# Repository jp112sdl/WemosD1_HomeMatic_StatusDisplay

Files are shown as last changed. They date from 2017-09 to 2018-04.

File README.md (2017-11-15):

# WemosD1 HomeMatic Status Display




## Zusammenfassung:
Ziel dieses Projektes ist der kostengünstige Bau einer Statusanzeige, ähnlich der von HomeMatic angebotenen.

Die Helligkeit der LEDs lässt sich mit einem Taster in 25 Stufen einstellen.

**2 Bilder des ersten Prototypen:**<br>
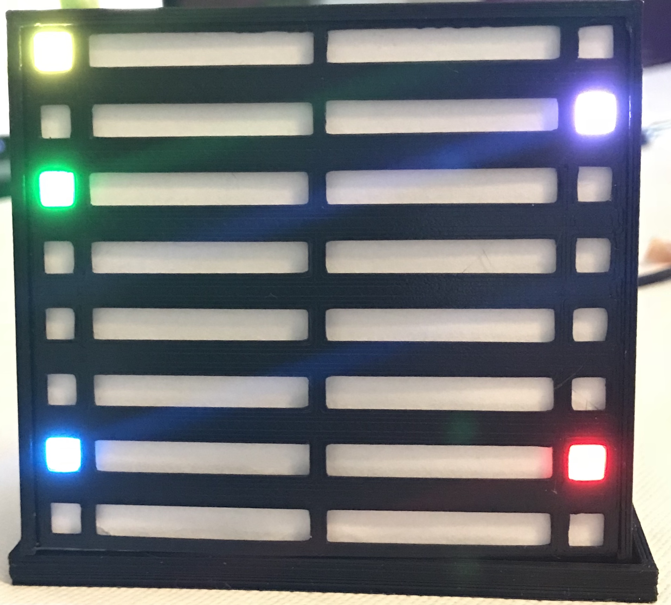
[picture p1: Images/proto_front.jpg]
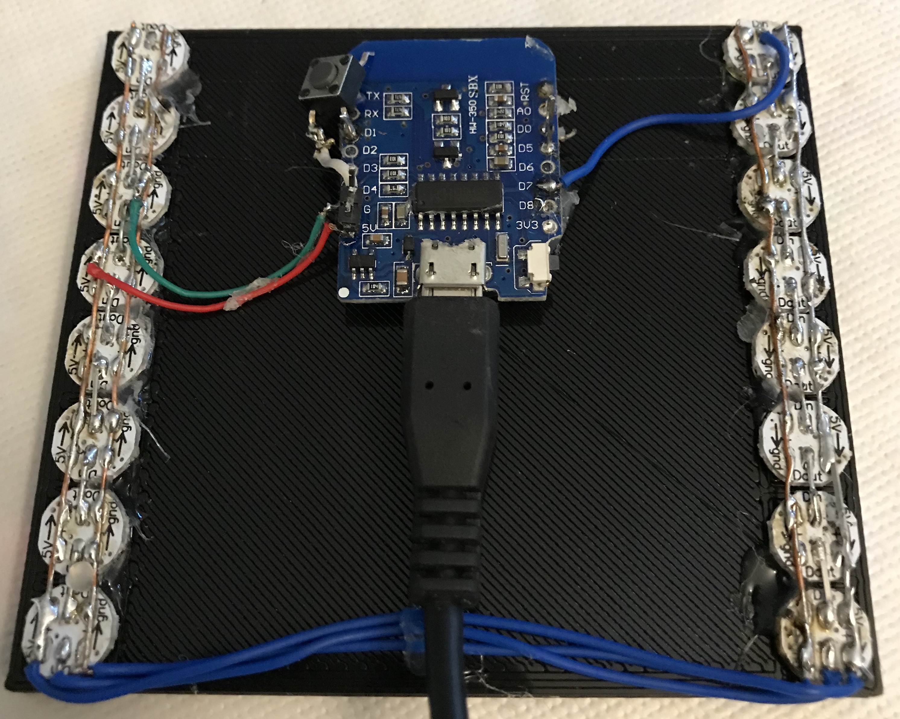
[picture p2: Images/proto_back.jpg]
 

**JETZT NEU: Mit Unterstützung von 16 Tasterkanälen!**<br>
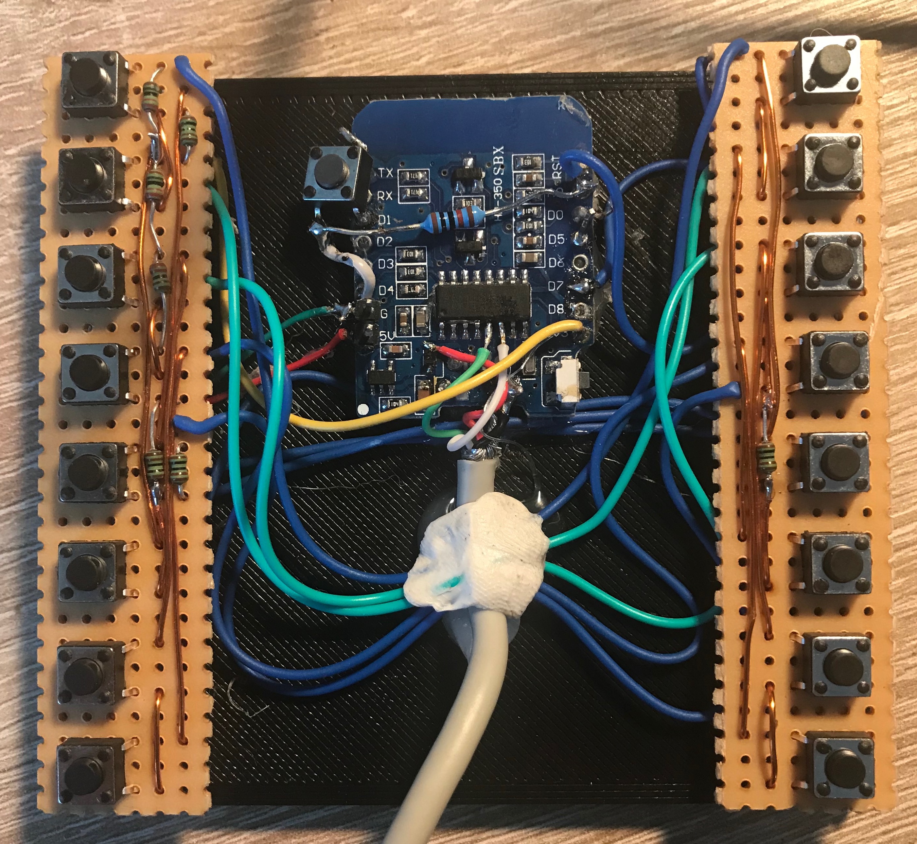
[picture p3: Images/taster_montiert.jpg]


Die komplette Nachbauanleitung findet ihr im [Wiki](https://github.com/jp112sdl/WemosD1_HomeMatic_StatusDisplay/wiki)

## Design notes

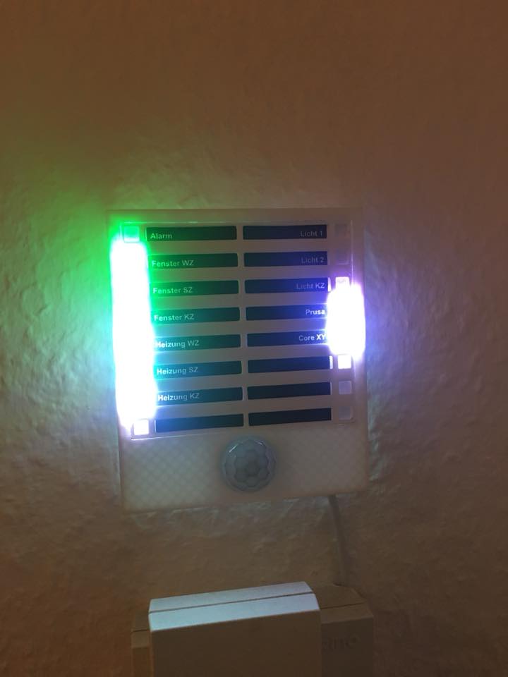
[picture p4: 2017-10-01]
Images/mw/mw_front.jpg

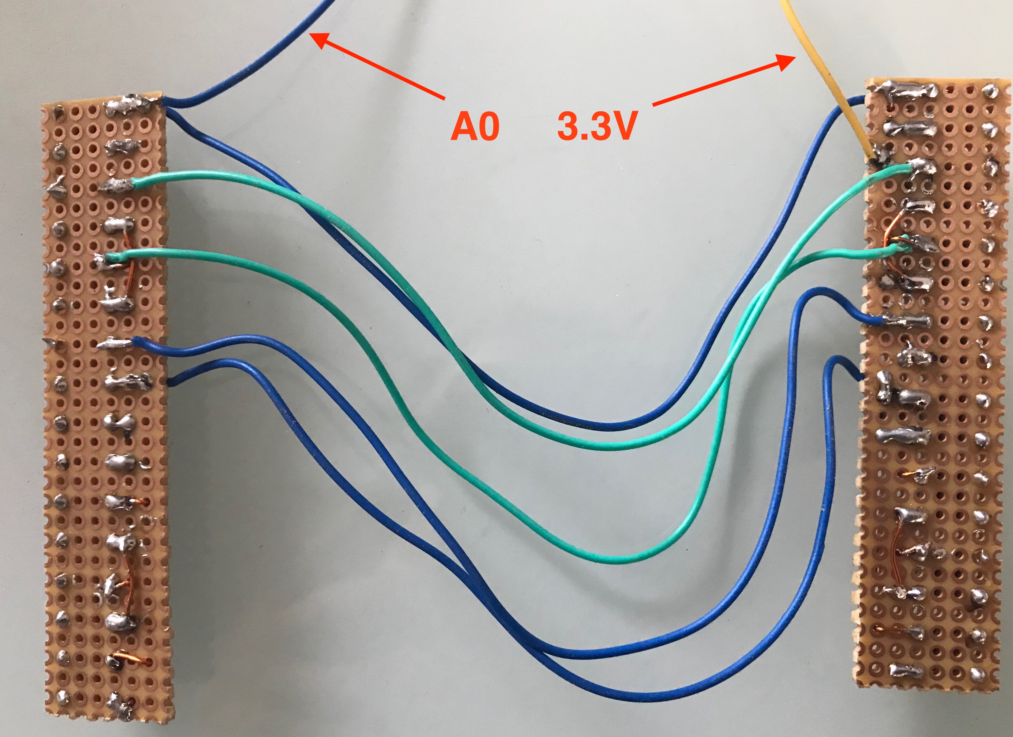
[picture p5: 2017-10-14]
Images/taster_hinten.jpg

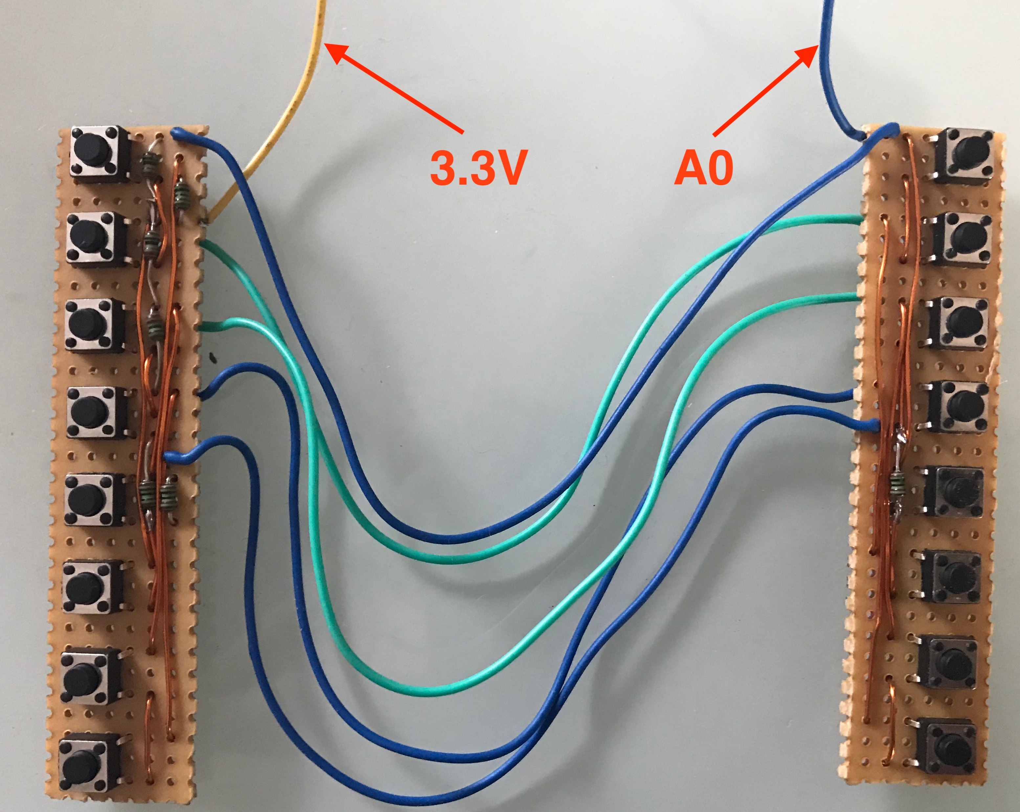
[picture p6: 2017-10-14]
Images/taster_vorn.jpg

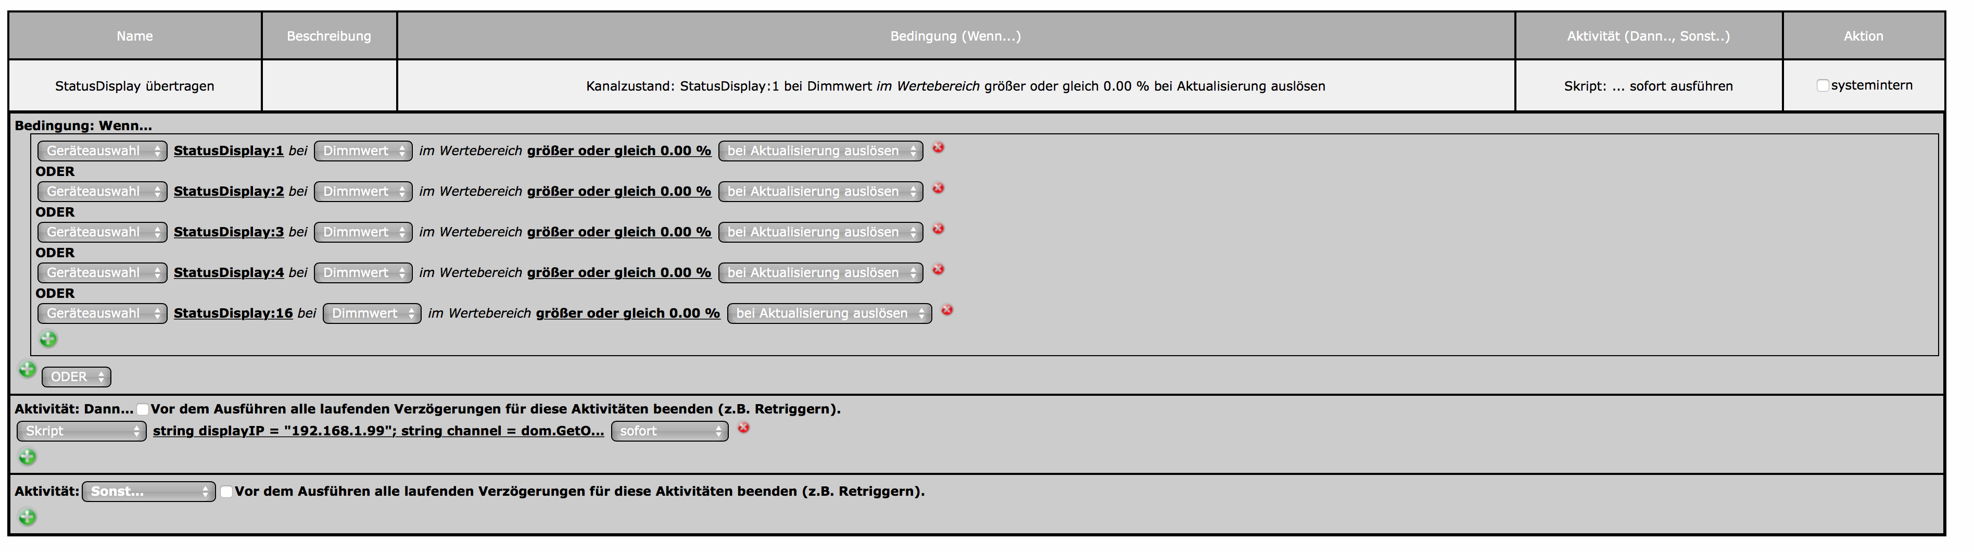
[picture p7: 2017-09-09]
Images/HomeMatic_Programm.png

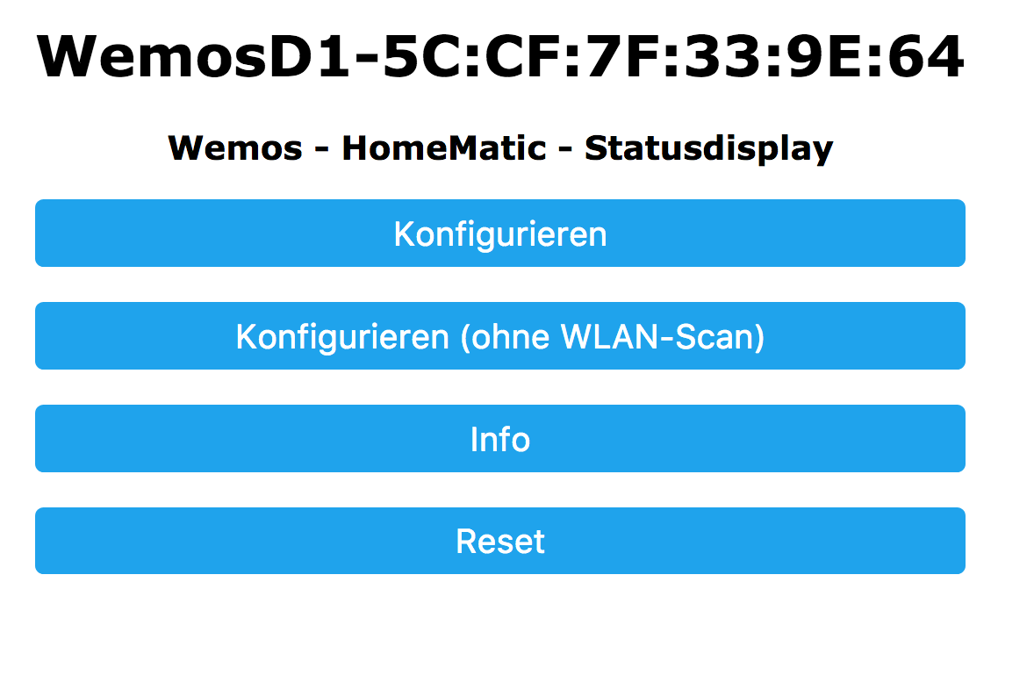
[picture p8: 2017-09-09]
Images/config_start.png

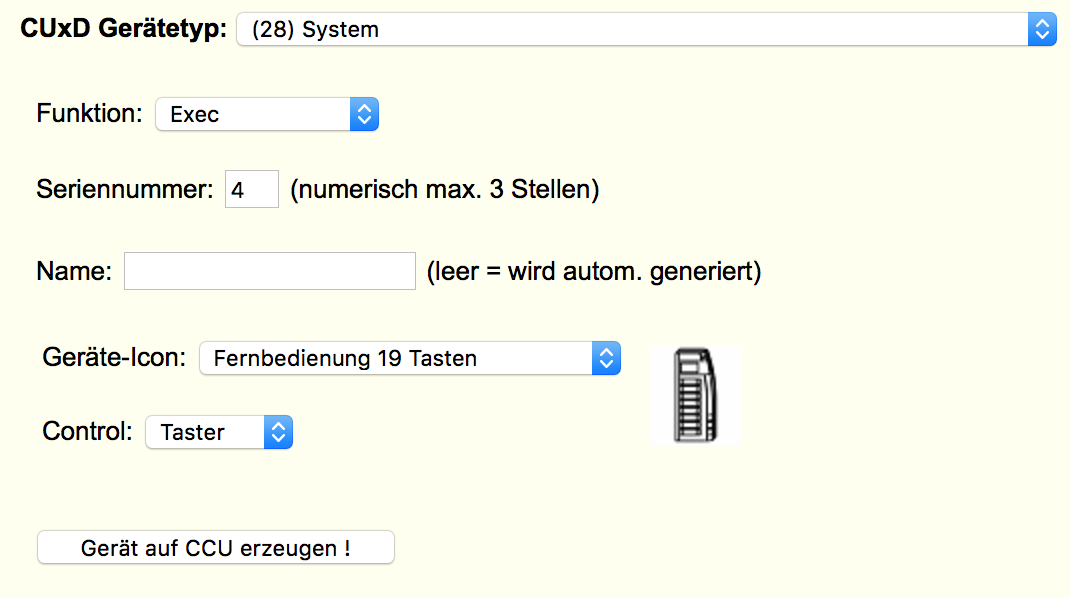
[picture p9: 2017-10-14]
Images/taster_cuxd28.png

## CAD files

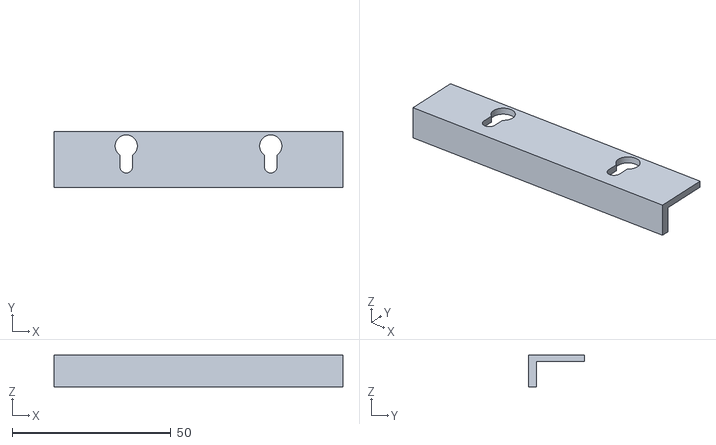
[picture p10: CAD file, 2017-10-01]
Images/mw/mw_StatusDisplay-teil-2.stl
91.0 x 17.5 x 10.0

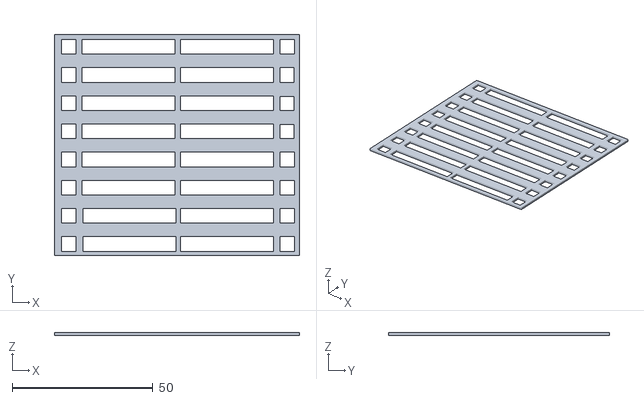
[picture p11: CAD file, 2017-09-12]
Images/Rasterplatte.stl
87.0 x 78.5 x 1.00

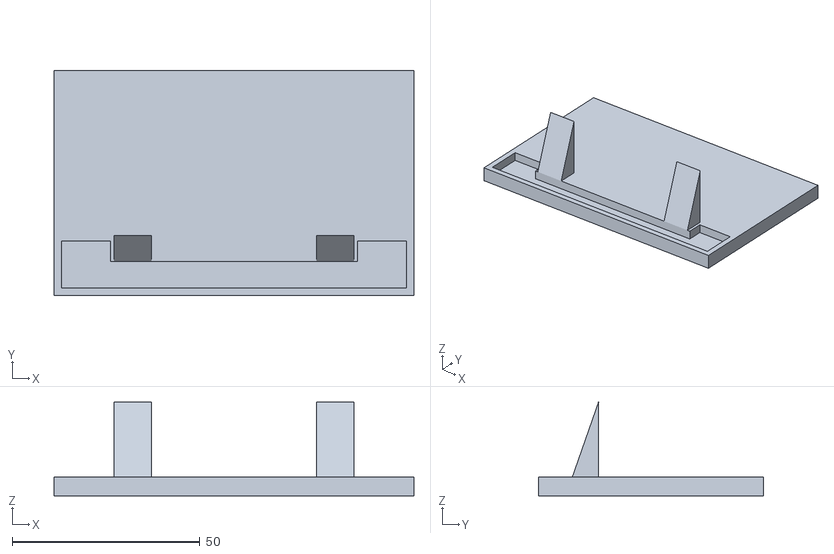
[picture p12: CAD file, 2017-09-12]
Images/Grundplatte.stl
96.0 x 60.0 x 25.0

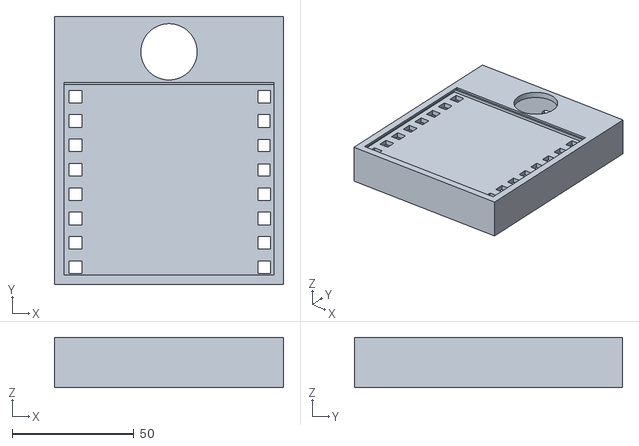
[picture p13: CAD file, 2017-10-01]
Images/mw/mw_StatusDisplay.stl
94.0 x 110.0 x 20.6

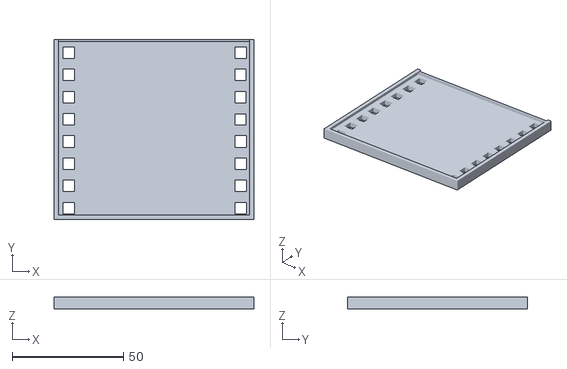
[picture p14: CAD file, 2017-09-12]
Images/Front.stl
90.0 x 81.0 x 5.60

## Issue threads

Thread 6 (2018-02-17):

Taster ohne Funktion

Michel83, 2018-02-17:
Hi,
gibt es was, was ich bei den 16 Tastern noch prüfen kann ich habe sie nach Anleitung angelernt was auch mit der grünen LED bestätigt wurde.
Aber ich bekomme sie nicht zum schalten über die CCU, Gerät ist richtig angelegt und auch überprüft.

Die Statusanzeige Funktioniert ohne Probleme

jp112sdl, 2018-02-17:
Hallo @Michel83 ,

kannst du bitte einen seriellen Log einfügen?
Bitte komplett vom Boot des Gerätes bis zum Drücken eines Tasters.
Vielleicht kann ich daraus schon was erkennen.

Wie man sowas macht, ist hier in einem [Youtube-Video](https://www.youtube.com/watch?v=dO-BMOzNKcI) erklärt.
Bei Speed muss 115200 eingetragen werden.
*Die zusätzlichen Einstellungen ab 1:07 min. brauchst du nicht verändern und kannst einfach schon auf "Open" klicken.*

Nachdem du Open geklickt hast, betätigst du den kleinen schwarzen Taster auf der WemosD1-Platine.
Nun siehst du in Putty die Log-Ausgaben.

Michel83, 2018-02-17:
Grade gemacht, ich glaube der Wemos vergisst irgendwie die Taster Positionen wenn ich den taster eins nach dem Anlernen drücke erkennt er mal 2 mal 5 usw sieht man schön im Log

`
▒
l▒
c|▒▒▒▒c▒c▒▒oo▒doo▒▒▒cp▒dslslp▒o▒▒d▒▒co▒|d▒▒c▒▒oo▒d▒▒d`▒gg
l`gs▒▒▒g
c
▒ds▒▒g
c
▒d▒▒l▒p▒▒d▒n▒Programmstart...
mounting FS...
mounted file system
reading config file
opened config file
{"ip":"192.168.178.55","netmask":"255.255.255.0","gw":"192.168.178.1","ccuip":"192.168.178.70","devicename":"StatusDisplay_1","numleds":16,"eorder":66,"brightness":35,"restorestate":true,"pirtoccu":false,"dimBlink":7,"ledkeys":[746,739,716,709,695,689,682,690,1024,1024,1024,757,764,771,764,756],"color0":"00FF00","color1":"F39C12","color2":"FF0000","color3":"FFFFFF","color4":"0000FF","color5":"00FF00","color6":"F39C12","color7":"FF0000","color8":"FFFFFF","color9":"0000FF"}
parsed json
*WM: Adding parameter
*WM:
*WM: Adding parameter
*WM: numleds
*WM: Adding parameter
*WM: rgborder
*WM: Adding parameter
*WM:
*WM: Adding parameter
*WM: ccuip
*WM: Adding parameter
*WM: devicename
*WM: Adding parameter
*WM: restorestate
*WM: Adding parameter
*WM: pirtoccu
*WM: Adding parameter
*WM:
*WM: Adding parameter
*WM: color1
*WM: Adding parameter
*WM: color2
*WM: Adding parameter
*WM: color3
*WM: Adding parameter
*WM: color4
*WM: Adding parameter
*WM: color5
*WM: Adding parameter
*WM: color6
*WM: Adding parameter
*WM: color7
*WM: Adding parameter
*WM: color8
*WM: Adding parameter
*WM: color9
*WM: Adding parameter
*WM: color10
*WM: Adding parameter
*WM:
*WM: Adding parameter
*WM: dimblink
*WM: Adding parameter
*WM:
*WM: Adding parameter
*WM: custom_ip
*WM: Adding parameter
*WM: custom_netmask
*WM: Adding parameter
*WM: custom_gw
*WM:
*WM: AutoConnect
*WM: Connecting as wifi client...
*WM: Custom STA IP/GW/Subnet
*WM: 192.168.178.55
*WM: Using last saved values, should be faster
*WM: Connection result:
*WM: 0
*WM: SET AP STA
AP-Modus ist aktiv!
*WM:
*WM: Configuring access point...
*WM: WemosD1-A0:20:A6:0A:2F:21
*WM: AP IP address:
*WM: 192.168.4.1
*WM: HTTP server started
*WM: Request redirected to captive portal
*WM: Request redirected to captive portal
*WM: Handle root
*WM: Reset
*WM: Sent reset page

 ets Jan  8 2013,rst cause:2, boot mode:(3,7)

load 0x4010f000, len 1384, room 16
tail 8
chksum 0x2d
csum 0x2d
v0c897c37
~ld
   Programmstart...
mounting FS...
mounted file system
reading config file
opened config file
{"ip":"192.168.178.55","netmask":"255.255.255.0","gw":"192.168.178.1","ccuip":"192.168.178.70","devicename":"StatusDisplay_1","numleds":16,"eorder":66,"brightness":35,"restorestate":true,"pirtoccu":false,"dimBlink":7,"ledkeys":[746,739,716,709,695,689,682,690,1024,1024,1024,757,764,771,764,756],"color0":"00FF00","color1":"F39C12","color2":"FF0000","color3":"FFFFFF","color4":"0000FF","color5":"00FF00","color6":"F39C12","color7":"FF0000","color8":"FFFFFF","color9":"0000FF"}
parsed json
*WM: Adding parameter
*WM:
*WM: Adding parameter
*WM: numleds
*WM: Adding parameter
*WM: rgborder
*WM: Adding parameter
*WM:
*WM: Adding parameter
*WM: ccuip
*WM: Adding parameter
*WM: devicename
*WM: Adding parameter
*WM: restorestate
*WM: Adding parameter
*WM: pirtoccu
*WM: Adding parameter
*WM:
*WM: Adding parameter
*WM: color1
*WM: Adding parameter
*WM: color2
*WM: Adding parameter
*WM: color3
*WM: Adding parameter
*WM: color4
*WM: Adding parameter
*WM: color5
*WM: Adding parameter
*WM: color6
*WM: Adding parameter
*WM: color7
*WM: Adding parameter
*WM: color8
*WM: Adding parameter
*WM: color9
*WM: Adding parameter
*WM: color10
*WM: Adding parameter
*WM:
*WM: Adding parameter
*WM: dimblink
*WM: Adding parameter
*WM:
*WM: Adding parameter
*WM: custom_ip
*WM: Adding parameter
*WM: custom_netmask
*WM: Adding parameter
*WM: custom_gw
*WM:
*WM: AutoConnect
*WM: Connecting as wifi client...
*WM: Custom STA IP/GW/Subnet
*WM: 192.168.178.55
*WM: Using last saved values, should be faster
*WM: Connection result:
*WM: 0
*WM: SET AP STA
AP-Modus ist aktiv!
*WM:
*WM: Configuring access point...
*WM: WemosD1-A0:20:A6:0A:2F:21
*WM: AP IP address:
*WM: 192.168.4.1
*WM: HTTP server started
*WM: Request redirected to captive portal
*WM: Request redirected to captive portal
*WM: Request redirected to captive portal
*WM: Request redirected to captive portal
*WM: Handle root
*WM: Scan done
*WM: DUP AP: WLAN 7270
*WM: DUP AP: WLAN 7270
*WM: WLAN 7270
*WM: -57
*WM: HZN246152378
*WM: -67
*WM: WLAN-218760
*WM: -79
*WM: AndroidAP
*WM: -90
*WM: devolo-e3c
*WM: -91
*WM: Sent config page
*WM: Request redirected to captive portal
*WM: Request redirected to captive portal
*WM: WiFi save
*WM: Parameter
*WM:
*WM:
*WM: Parameter
*WM: numleds
*WM: 16
*WM: Parameter
*WM: rgborder
*WM: 66
*WM: Parameter
*WM:
*WM:
*WM: Parameter
*WM: ccuip
*WM: 192.168.178.70
*WM: Parameter
*WM: devicename
*WM: StatusDisplay_1
*WM: Parameter
*WM: restorestate
*WM: 1
*WM: Parameter
*WM: pirtoccu
*WM:
*WM: Parameter
*WM:
*WM:
*WM: Parameter
*WM: color1
*WM: 00FF00
*WM: Parameter
*WM: color2
*WM: F39C12
*WM: Parameter
*WM: color3
*WM: FF0000
*WM: Parameter
*WM: color4
*WM: FFFFFF
*WM: Parameter
*WM: color5
*WM: 0000FF
*WM: Parameter
*WM: color6
*WM: 00FF00
*WM: Parameter
*WM: color7
*WM: F39C12
*WM: Parameter
*WM: color8
*WM: FF0000
*WM: Parameter
*WM: color9
*WM: FFFFFF
*WM: Parameter
*WM: color10
*WM: 0000FF
*WM: Parameter
*WM:
*WM:
*WM: Parameter
*WM: dimblink
*WM: 7
*WM: Parameter
*WM:
*WM:
*WM: Parameter
*WM: custom_ip
*WM: 192.168.178.55
*WM: Parameter
*WM: custom_netmask
*WM: 255.255.255.0
*WM: Parameter
*WM: custom_gw
*WM: 192.168.178.1
*WM: Sent wifi save page
*WM: Connecting to new AP
*WM: Connecting as wifi client...
*WM: Custom STA IP/GW/Subnet
*WM: 192.168.178.55
*WM: Connection result:
*WM: 4
*WM: Failed to connect.
*WM: Request redirected to captive portal
*WM: Request redirected to captive portal
*WM: Handle root
*WM: Scan done
*WM: DUP AP: WLAN 7270
*WM: DUP AP: WLAN 7270
*WM: WLAN 7270
*WM: -57
*WM: HZN246152378
*WM: -73
*WM: Lasyab
*WM: -92
*WM: Sent config page
*WM: Request redirected to captive portal
*WM: Request redirected to captive portal
*WM: Handle root
*WM: Request redirected to captive portal
*WM: Handle root
*WM: Scan done
*WM: DUP AP: WLAN 7270
*WM: DUP AP: WLAN 7270
*WM: WLAN 7270
*WM: -55
*WM: HZN246152378
*WM: -73
*WM: devolo-c59
*WM: -93
*WM: Lasyab
*WM: -93
*WM: Telekom_FON
*WM: -94
*WM: Sent config page
*WM: Request redirected to captive portal
*WM: Request redirected to captive portal
*WM: WiFi save
*WM: Parameter
*WM:
*WM:
*WM: Parameter
*WM: numleds
*WM: 16
*WM: Parameter
*WM: rgborder
*WM: 66
*WM: Parameter
*WM:
*WM:
*WM: Parameter
*WM: ccuip
*WM: 192.168.178.70
*WM: Parameter
*WM: devicename
*WM: StatusDisplay_1
*WM: Parameter
*WM: restorestate
*WM: 1
*WM: Parameter
*WM: pirtoccu
*WM:
*WM: Parameter
*WM:
*WM:
*WM: Parameter
*WM: color1
*WM: 00FF00
*WM: Parameter
*WM: color2
*WM: F39C12
*WM: Parameter
*WM: color3
*WM: FF0000
*WM: Parameter
*WM: color4
*WM: FFFFFF
*WM: Parameter
*WM: color5
*WM: 0000FF
*WM: Parameter
*WM: color6
*WM: 00FF00
*WM: Parameter
*WM: color7
*WM: F39C12
*WM: Parameter
*WM: color8
*WM: FF0000
*WM: Parameter
*WM: color9
*WM: FFFFFF
*WM: Parameter
*WM: color10
*WM: 0000FF
*WM: Parameter
*WM:
*WM:
*WM: Parameter
*WM: dimblink
*WM: 7
*WM: Parameter
*WM:
*WM:
*WM: Parameter
*WM: custom_ip
*WM: 192.168.178.55
*WM: Parameter
*WM: custom_netmask
*WM: 255.255.255.0
*WM: Parameter
*WM: custom_gw
*WM: 192.168.178.1
*WM: Sent wifi save page
*WM: Connecting to new AP
*WM: Connecting as wifi client...
*WM: Custom STA IP/GW/Subnet
*WM: 192.168.178.55
*WM: Connection result:
*WM: 3
Should save config
Wifi Connected
CUSTOM STATIC IP: 192.168.178.55 Netmask: 255.255.255.0 GW: 192.168.178.1
Custom IP Address is set!
saving config
{"ip":"192.168.178.55","netmask":"255.255.255.0","gw":"192.168.178.1","ccuip":"192.168.178.70","devicename":"StatusDisplay_1","numleds":16,"eorder":66,"brightness":35,"restorestate":true,"pirtoccu":false,"dimBlink":7,"ledkeys":[746,739,716,709,695,689,682,690,1024,1024,1024,757,764,771,764,756],"color0":"00FF00","color1":"F39C12","color2":"FF0000","color3":"FFFFFF","color4":"0000FF","color5":"00FF00","color6":"F39C12","color7":"FF0000","color8":"FFFFFF","color9":"0000FF"}

 ets Jan  8 2013,rst cause:2, boot mode:(3,7)
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
jp112sdl, 2018-02-17:
Ich habe tatsächlich einen Fehler im Code gefunden und *hoffentlich* behoben.

Versuch es bitte mal hiermit:
[WemosD1_HomeMatic_StatusDisplay.ino.d1_mini.bin.zip](https://github.com/jp112sdl/WemosD1_HomeMatic_StatusDisplay/files/1733641/WemosD1_HomeMatic_StatusDisplay.ino.d1_mini.bin.zip)

Was mir noch auffällt: Deine Widerstandswerte liegen alle sehr dicht beieinander. Da kann es zu Fehlauswertungen kommen.
Deine:
`[684,657,652,664,653,628,641,635,1024,1024,1024,674,696,688,681,692]`
Meine:
`[864,845,830,816,927,893,882,881,896,913,926,959,979,994,1019,1020]`

Evtl. hast du noch irgendwo einen Dreher drin...

Michel83, 2018-02-17:
Ja es Funktioniert super vielen Dank für den schnellen Support !!!!

Gruß

jp112sdl, 2018-02-17:
Danke für das positive Feedback!

Michel83, 2018-02-17:
Den Fehler mit den Tastern bei mir habe ich gefunden nur leider beheben ist schwierige da die Heißklebepistole schneller war. Aber in der 2 Version.

Könnte man die Taster auch noch in der Webui hinzufügen ? und eventuell auch Beschriftungsfelder für die LED`s dann wäre das Webui Perfekt und man könnte dieses sogar auf anderen Geräten über http anzeigen z.b. Neo Creator.

Danke nochmal für den Support

Gruß

jp112sdl, 2018-02-17:
Die Weboberfläche ist rudimentär und eigentlich nur nebenbei entstanden.

Wenn ich mal viel Langeweile hab (vielleicht im nächsten Winter ;) ) denk ich mal drüber nach :D

Michel83, 2018-02-20:
Kein Problem, die Anzeige ist auch so schon Top, super sache !!!

Gibt es eigentlich eine Anleitung oder Readme für WemosD1_HomeMatic_FunkGong ? oder habe ich sie einfach nicht gefunden ?

Sorry das ich das einfach jetzt hier mal so reinschreibe

jp112sdl, 2018-02-20:
Gibts nicht. Hab ich nur nach Anregung von [Braindead](https://github.com/braindead1/WemosD1_MP3Gong) für mich abgewandelt und um einen rotierenden/umlaufenden LED-Kranz erweitert.

Closed 2018-02-17.

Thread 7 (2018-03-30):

Taster

Michel83, 2018-03-30:
Hi,

ich hätte noch ein kleines Problem wo ich nicht weiter komme.
Es geht um die Taster es ist jetzt so das die Werte bei allen unterschiedlich sind allerdings werden sie von dem Wemos nicht erkannt er sagt immer bei jedem taster 1024 erkannt.

Hier ein paar Bilder wenn ich am A0 des Wemos mit dem Multimeter messe, was ich festgestellt habe das es ein moment dauert bis der Multimeter den Wert anzeigt.

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

jp112sdl, 2018-03-30:
Schließ den + mal bitte statt an 5V an den **3.3V** Pin des Wemos. Ich glaub das ist in meinem Schaltplan falsch.

Michel83, 2018-03-30:
Super danke das war es, läuft :-)

jp112sdl, 2018-03-30:
Danke für den Hinweis. Habs im Schaltplan jetzt auch geändert.

Michel83, 2018-03-30:
Kein Problem, echt super das Teil.

Die LED's sind noch ein wenig Hell :-)

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

jp112sdl, 2018-03-30:
> Die LED's sind noch ein wenig Hell

Das kannst du ja beliebig einstellen :)

Closed 2018-03-30.

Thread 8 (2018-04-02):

Display friert ein

Michel83, 2018-04-02:
Hi,

ich muss leider nochmal nerven. Habe noch das Problem das der Wemos hin und wieder nicht mehr erreichbar ist. Hatte dies auch schon bei meiner ersten Bastel version, dachte es läge aber an meinem Wemos weil eben Bastel.

Aber mein jetziger macht das gleiche, es ist dann so das auch die LED´s nicht mehr aktualisiert werden erst wenn ich am Display irgendeine taste drücke ist es so als ob der Wemos neu startet also die Blinkreinfolge der LED´s und danach alles wieder in Ordnung.

Gruß
Mike

jp112sdl, 2018-04-02:
Hast du den Code selbst kompiliert oder die .bin geflasht?

Michel83, 2018-04-02:
Die .bin geflasht wie in der Anleitung

jp112sdl, 2018-04-02:
Ich vermute, das Problem hängt mit esp8266/Arduino#2330 zusammen.

Teste bitte mal diese hier:
[WemosD1_HomeMatic_StatusDisplay.ino.d1_mini.bin.zip](https://github.com/jp112sdl/WemosD1_HomeMatic_StatusDisplay/files/1867526/WemosD1_HomeMatic_StatusDisplay.ino.d1_mini.bin.zip)

Michel83, 2018-04-02:
Ich teste

Michel83, 2018-04-02:
Bis jetzt ist noch alles gut, ist das `WiFi.setSleepMode(WIFI_NONE_SLEEP);` die Änderung in dem WLAN gewesen ?
Weil ich habe noch einen Wemos als ir remote der die gleichen Bauchweh hat dann würde ich das da auch mal versuchen

jp112sdl, 2018-04-02:
Hab die Änderungen gepusht, damit du nachschauen kannst

Michel83, 2018-04-04:
Ich denke es läuft seit dem keine Einfrierer mehr, danke für die Anpassung.
Ich glaub bis ich da alles verstehe dauert noch ein Moment :-)

Gruß
Mike

jp112sdl, 2018-04-04:
Perfekt 👍
Dann viel Spaß damit - ich mach hier zu :)

Closed 2018-04-04.

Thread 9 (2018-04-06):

WiFi Ändern geht nicht bzw. wird ignoriert

guybrushix, 2018-04-06:
Hallo,

ich möchte bei dem Display das WiFi ändern leider nutzt der Wemos immer das alte egal ich wie oft ich das ändere über AP Modus. Das selbe Problem habe ich mit einem (nicht allen) Sonoff POW.

gibt es irgend einen weg ohne komplettes neues flashen ?

Danke im Voraus & Gruss

Michael

jp112sdl, 2018-04-06:
Nein, die Wifi Zugangsdaten liegen in einem anderen Speicherbereich, der beim Flashen nicht überschrieben wird. Ein Neuflashen würde also auch nicht die Wifi Daten überschreiben.

Evtl. ist ein Sonderzeichen im Passwort, das bei der Übergabe im HTTP-Get Probleme macht... Die Zugangsdaten werden erst dann gespeichert, wenn beim Speichern auch eine Verbindung zum WLAN mit den eingegebenen Daten hergestellt werden kann. Klappt dies nicht, bleiben die alten erhalten.

jp112sdl, 2018-04-06:
Es könnte jedoch auch mit einem Bug im Wifi Stack selbst zusammenhängen...
Hab da grad was gefunden. esp8266/arduino#4476

guybrushix, 2018-04-07:
Okay dann macht flashen keinen sinn.
Zu

> Evtl. ist ein Sonderzeichen im Passwort, das bei der Übergabe im HTTP-Get Probleme macht...
 im neuen WLAN ist das Passwort eine reine Buchstaben Kombination.

guybrushix, 2018-04-07:
Hallo ich musste wohl das andere WiFi komplett ausschalten sonst hat er sich immer wieder mit dem alten verbunden. Nachdem das alte aus war hat sich das display mit dem neuen WiFi verbunden.

Closed 2018-04-07.

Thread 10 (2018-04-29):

2 Display Kanal 8

Michel83, 2018-04-29:
Ich habe gestern ein zweites Display quasi in Betrieb genommen allerdings ohne taster. Das Problem ist der Kanal 8 es funktionieren alle bis auf diesen. Wenn ich jetzt den Wert beim ersten Display des Kanal 8 verändere, ändert sich die Anzeige auf beiden Displays.

Hab ich irgendwas falsch gemacht ?

jp112sdl, 2018-04-29:
Das kann ich nur anhand der beschriebenen Symptomatik schwer beurteilen.

Evtl. versehentlich IP doppelt vergeben?
Arbeitest du mit UDP oder HTTP Steuerung?
Ist der Gerätename eindeutig?

Michel83, 2018-04-29:
Stimmt recht wenige Informationen

Also die HTTP Steuerung Funktioniert grade getestet, es passiert nur wenn ich diese über die CCU schalte
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

Es passiert auch wenn ich es direct in den Geräten bediene

jp112sdl, 2018-04-29:
Dann kommt ja nur eins in Frage:
Du hast ja 2 Programme. Für jedes StatusDisplay eines.
In den Programmen hast du jeweils alle 16 Kanäle des CUxD Geräts drin.
Ich vermute, dass du versehentlich in Programm 2 für StatusDisplay_2 auch noch einen Kanal von StatusDisplay_1 mit hinzugefügt hast. Oder umgekehrt - in Programm 1 für StatusDisplay_1 versehentlich einen Kanal aus StatusDisplay_2

Michel83, 2018-04-29:
Die Programme sind in Ordnung kann auch noch mal screenshots einstellen, was ich eben auch festgestellt habe das bei der Manuellen Bedienung in der CCU  der Kanal 8 bei dem zweiten Display auch nicht funktioniert. Sondern nur wenn ich den Kanal bei dem ersten Display Wechsel. Ich hatte auch grade zum test das Programm nochmal gelöscht und neu angelegt hat aber auch nichts geholfen

jp112sdl, 2018-04-29:
Also wenn du bspw über einen Browser den Status setzt mit
`http://<ip_display_1>/set?led=8&dim=10`
dann ändert sich die Farbe auf Kanal 8 **nur von  Display 1** entsprechend dem Dimmerwert 10...19?
Und wenn du mit
`http://<ip_display_2>/set?led=8&dim=10`
das selbe für Display 2 machst, ändert sich auch **nur auf Display 2** der Kanal 8?

Michel83, 2018-04-29:
Jetzt habe ich grade nochmal das Programm des ersten Displays gelöscht und neu eingegeben jetzt läuft es :-/ anscheinend ist in der CCU beim kopieren des Programms von Display 1 zu 2 was schief gegangen.

Danke für den Support !!!
Grüße

jp112sdl, 2018-04-29:
Hehe, ja also einen Fehler im Code hatte ich auch ausgeschlossen. Es konnte nur irgendwo von der Zentralensteuerung kommen...

Wenns jetzt geht ist ja alles gut :)
Viel Spaß damit!

Michel83, 2018-04-29:
Danke noch mal, ich habe auch eine weitere Version des Displays zum Einbau ohne taster gezeichnet https://www.thingiverse.com/thing:2882182

jp112sdl, 2018-04-29:
Hab ich mit in der Wiki-Navbar aufgenommen.
https://github.com/jp112sdl/WemosD1_HomeMatic_StatusDisplay/wiki/Housing_Michel83
Danke.

Closed 2018-04-29.

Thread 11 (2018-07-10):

Werte von CCU beim Start laden?

spaceduck518, 2018-07-10:
wie funktioniert das laden der aktuellen Werte aus der CCU? Das aktivieren der Option bewirkt kein holen der Werte beim Start des Displays. IP ist korrekt.

jp112sdl, 2018-07-10:
Der Gerätename muss identisch sein mit dem Namen des CUxD Gerätes, das die Dimmerkanäle hat.
Angenommen du trägst als Gerätenamen **StatusDisplay1** ein, dann muss das CUxD Gerät auch so heißen.
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

Beim Starten wird die Adresse des CUxD-Geräts mit dem Gerätenamen des Statusdisplays gesucht und anschließend werden die Werte der einzelnen Kanäle abgefragt.

spaceduck518, 2018-07-13:
Beide Namen sind identisch, das hatte ich bereits überprüft. Gibt es sonst noch Einstellungen in der CCU oder im CuxD die hier greifen könnten?

spaceduck518, 2018-07-13:
Habe gerade mal den Namen auf beiden Seiten von "StatusDisplay" auf "StatusDisplay1" geändert - funktioniert! Nur "StatusDisplay" ohne Nummer funktioniert nicht. Kannst Du das evtl. ebenfalls bei Dir mal testen / reproduzieren?

spaceduck518, 2018-07-13:
Nein, der Name existiert nicht doppelt, hatte ich ebenfalls schon geprüft. Aber ich kann mit dem workaround leben, kein Problem!

Jan

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

jp112sdl, 2018-07-13:
Ok, dann belassen wir es dabei?
Anderenfalls könntest du auch mal die seriellen Debugmeldungen am PC loggen, dann würden wir wahrscheinlich mehr sehen, weshalb es nicht klappt.

spaceduck518, 2018-07-13:
Ja, wir lassen es so. Ich werde bei Gelegenheit mal via rs232 schauen was da passiert und melde mich dann nochmal.

Danke!

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

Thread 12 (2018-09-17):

Farbe wechseln, nur eine LED möglich?

MathiasJZ, 2018-09-17:
Ich möchte mir so ein Status-Display in der Nähe des Balkonfensters aufhängen.
Aber es soll nur eine LED haben, die von grün auf rot wechselt.
Das ganze soll als "Status Display" für meinen "Einbruchmelder" dienen, wenn scharf geschaltet wurde.
D.h. wenn die Lampe grün leuchtet, darf die Türe geöffnet werden, wenn rot, dann nicht.
Leider gibt es wohl keine Möglichkeit, Fragen zu stellen. Im homematic-forum habe ich diesbezüglich nichts gefunden.
Ein echtes 16-Kanal-Statusdisplay kommt für mich nicht in Frage. ich habe die Visualisierung des Hauses schon per IObroker und Wandtablet umgesetzt.
Gruß,
Mathias

MathiasJZ, 2018-09-18:
Dankeschön für die Antwort.
Da werde ich mich gleich drum kümmern

Gruß
Mathias

Am 18. September 2018 08:21:41 schrieb Jérôme <notifications@github.com>:
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

Closed 2018-09-21.

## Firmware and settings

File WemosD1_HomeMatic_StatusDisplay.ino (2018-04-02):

#include <ArduinoJson.h>
#include <ArduinoOTA.h>
#include <ESP8266HTTPClient.h>
#include <ESP8266HTTPUpdateServer.h>
#include <ESP8266WiFi.h>
#include <ESP8266WebServer.h>
#include <FastLED.h>
#include <FS.h>
#include <WiFiUdp.h>
#include "WM_Custom.h"
#include "global_css.h"
#include "webConfigHTML.h"

#define                       SERIALDEBUG
//#define                       WM_DEBUG_OUTPUT
//#define                       UDPDEBUG

#define CONFIG_PIN            D1
#define PIR_PIN               D5
#define WEBSERVER_PORT        80
#define UDPPORT             6690
#define HTTPGETTIMEOUT      2000 // 2 Sekunden Timeout für Anfragen an die CCU
#define KEYPRESSLONGMILLIS  1500 // ms für langen Tastendruck
#define KEYBOUNCEMILLIS      200 // ms Mindestzeit zwischen 2 Tastendrücken
#define KEYTOLERANCE          5 // +/-Toleranz für 16er Widerstands-/Tastermatrix

#ifdef UDPDEBUG
const char * SYSLOGIP = "192.168.1.251";
#define SYSLOGUDPPORT   514
#endif

enum _SyslogSeverity {
  _slEmergency,
  _slAlert,
  _slCritical,
  _slError,
  _slWarning,
  _slNotice,
  _slInformational,
  _slDebug
};

// FastLED
#define LED_PIN D7
#define LED_TYPE WS2812
#define MAX_LEDS 255
struct led_t {
  CRGB leds[MAX_LEDS];
  CRGB ledsBackup[MAX_LEDS];
  int  Colors[MAX_LEDS];
  bool Blink[MAX_LEDS];
  int  Keys[16] {1023, 1023, 1023, 1023, 1023, 1023, 1023, 1023, 1023, 1023, 1023, 1023, 1023, 1023, 1023, 1023};
} LEDConfig;

enum _EOrder {
  _RGB = 0012,
  _RBG = 0021,
  _GRB = 0102,
  _GBR = 0120,
  _BRG = 0201,
  _BGR = 0210
};
#define IP_SIZE        16
#define VARIABLE_SIZE  100

struct globalconfig_t {
  byte LedBrightness = 255;
  int SelectedEOrder = _RGB;
  int NumLeds =        16;
  char CcuIp[IP_SIZE];
  char DeviceName[VARIABLE_SIZE];
  bool RestoreStateFromCCU = false;
  bool PIRtoCCU = false;
  byte DimBlink = 11;
} GlobalConfig;

#define HEXARRAY_SIZE  24
#define COLOR_COUNT    10

String Dimmer2ColorDefinition[COLOR_COUNT] {
  "00FF00", "F39C12", "FF0000", "FFFFFF", "0000FF", "00FF00", "F39C12", "FF0000", "FFFFFF", "0000FF"
};

enum DisplayStates {
  Sleep,
  Wake
};

ESP8266WebServer WebServer(WEBSERVER_PORT);
ESP8266HTTPUpdateServer httpUpdater;

//UDP
struct udp_t {
  WiFiUDP UDP;
  char incomingPacket[255];
} UDPClient;

//WifiManager - don't touch
byte configPortalTimeout    = 180;
bool shouldSaveConfig       = false;
String configJsonFile   = "config.json";
char ip[IP_SIZE]             = "0.0.0.0";
char netmask[IP_SIZE]        = "0.0.0.0";
char gw[IP_SIZE]             = "0.0.0.0";
boolean startWifiManager    = false;
bool WiFiConnected = false;

int DisplayTimeoutSeconds = 0;
unsigned long LastDisplayTimeOutMillis = 0;
unsigned long LastBlinkMillis = 0;
bool OTAStart = false;
bool DisplayState = Wake;
bool blinkState = false;
bool UDPReady = false;
volatile byte PIRInterruptDetected = 0;
bool ConfigKeyPress = false;
bool ConfigKeyPressLONG = false;
unsigned long ConfigKeyPressDownMillis = 0;
unsigned long LastMillisConfigKeyPress = 0;
unsigned long LastWiFiReconnectMillis = 0;

void setup() {
  pinMode(A0, INPUT);
  pinMode(CONFIG_PIN, INPUT_PULLUP);
  pinMode(LED_BUILTIN, OUTPUT);
  initPIR();

  digitalWrite(LED_BUILTIN, HIGH);
#ifdef SERIALDEBUG
  Serial.begin(115200);
#endif
  DEBUG("Programmstart...");

  if (digitalRead(CONFIG_PIN) == LOW) {
    DEBUG("Taster gedrückt - Config Mode wird gestartet!");
    startWifiManager = true;
    bool state = LOW;
    for (int i = 0; i < 7; i++) {
      state = !state;
      digitalWrite(LED_BUILTIN, state);
      delay(100);
    }
  }
  loadSystemConfig();

  if (doWifiConnect()) {
    DEBUG("WLAN erfolgreich verbunden!");
    printWifiStatus();
  } else ESP.restart();

  startWebServer();

  initUDPClient();

  initLEDs();

  showLedBootSequence();

  startOTAhandling();

  if (GlobalConfig.RestoreStateFromCCU)
    getValuesFromCCU();

  DEBUG(String(GlobalConfig.DeviceName) + " - Boot abgeschlossen, SSID = " + WiFi.SSID() + ", IP = " + String(IpAddress2String(WiFi.localIP())) + ", RSSI = " + WiFi.RSSI() + ", MAC = " + WiFi.macAddress(), "Setup", _slInformational);
}

void loop() {
  if (LastDisplayTimeOutMillis > millis())
    LastDisplayTimeOutMillis = millis();
  if (LastBlinkMillis > millis())
    LastBlinkMillis = millis();
  if (LastWiFiReconnectMillis > millis())
    LastWiFiReconnectMillis = millis();

  //Reconnect WiFi wenn nicht verbunden (alle 30 Sekunden)
  if (WiFi.status() != WL_CONNECTED) {
    WiFiConnected = false;
    if (millis() - LastWiFiReconnectMillis > 30000) {
      LastWiFiReconnectMillis = millis();
      DEBUG("WiFi Connection lost! Reconnecting...");
      WiFi.reconnect();
    }
  } else {
    if (!WiFiConnected) {
      DEBUG("WiFi reconnected!");
      WiFiConnected = true;
    }
  }

  ArduinoOTA.handle();

  if (!OTAStart) {
    WebServer.handleClient();

    handleUDP();

    handlePIR();

    handleKEY();

    if (DisplayTimeoutSeconds > 0 && DisplayState == Wake && millis() - LastDisplayTimeOutMillis > DisplayTimeoutSeconds * 1000) {
      LastDisplayTimeOutMillis = millis();
      DEBUG("Display Timeout", "loop()", _slInformational);
      setLedMode(Sleep);
    }

    if (millis() - LastBlinkMillis > 1000 && DisplayState == Wake) {
      LastBlinkMillis = millis();
      blinkState = !blinkState;
      for (int i = 0; i < GlobalConfig.NumLeds; i++) {
        LEDConfig.ledsBackup[i] = LEDConfig.leds[i];
        if (blinkState && LEDConfig.Blink[i]) {
          LEDConfig.leds[i] = CRGB::Black;
        }
      }
      FastLED.show();
      for (int i = 0; i < GlobalConfig.NumLeds; i++) {
        LEDConfig.leds[i] = LEDConfig.ledsBackup[i];
      }
    }

    //Tasterbedienung CONFIG_PIN
    if (digitalRead(CONFIG_PIN) == LOW) {
      if (!ConfigKeyPress) {
        ConfigKeyPressDownMillis = millis();
        if (millis() - LastMillisConfigKeyPress > KEYBOUNCEMILLIS) {
          LastMillisConfigKeyPress = millis();
          ConfigKeyPress = true;
        }
      }

      if ((millis() - ConfigKeyPressDownMillis) > KEYPRESSLONGMILLIS && !ConfigKeyPressLONG) {
        //PRESS_LONG
        DEBUG("ConfigKeyPress LONG", "loop()", _slInformational);
        ResistorConfigKeys();
        ConfigKeyPressLONG = true;
      }
    } else {
      if (ConfigKeyPress) {
        if ((millis() - ConfigKeyPressDownMillis) < KEYPRESSLONGMILLIS) {
          int brightness = GlobalConfig.LedBrightness;
          brightness = brightness + 25;
          if (brightness > 255) brightness = 10;
          DEBUG("ConfigKeyPress SHORT, setting brightness to " + String(brightness), "loop()", _slInformational);
          setLedBrightness(brightness);
          delay(10); //Entprellen
        }
      }
      ConfigKeyPress = false;
      ConfigKeyPressLONG = false;
    }
    delay(10); //wg. UDP
  }
}

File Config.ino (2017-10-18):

bool loadSystemConfig() {
  DEBUG("mounting FS...", "loadSystemConfig()", _slInformational);
  if (SPIFFS.begin()) {
    DEBUG("mounted file system", "loadSystemConfig()", _slInformational);
    if (SPIFFS.exists("/" + configJsonFile)) {
      DEBUG("reading config file", "loadSystemConfig()", _slInformational);
      File configFile = SPIFFS.open("/" + configJsonFile, "r");
      if (configFile) {
        DEBUG("opened config file", "loadSystemConfig()", _slInformational);
        size_t size = configFile.size();
        std::unique_ptr<char[]> buf(new char[size]);
        configFile.readBytes(buf.get(), size);
        DynamicJsonBuffer jsonBuffer;
        JsonObject& json = jsonBuffer.parseObject(buf.get());
#ifdef SERIALDEBUG
        json.printTo(Serial);
        Serial.println();
#endif
        if (json.success()) {
          DEBUG("parsed json", "loadSystemConfig()", _slInformational);
          ((json["ip"]).as<String>()).toCharArray(ip, IP_SIZE);
          ((json["netmask"]).as<String>()).toCharArray(netmask, IP_SIZE);
          ((json["gw"]).as<String>()).toCharArray(gw, IP_SIZE);
          ((json["ccuip"]).as<String>()).toCharArray(GlobalConfig.CcuIp, IP_SIZE);
          ((json["devicename"]).as<String>()).toCharArray(GlobalConfig.DeviceName, VARIABLE_SIZE);

          json["ledkeys"].asArray().copyTo(LEDConfig.Keys);

          GlobalConfig.RestoreStateFromCCU = json["restorestate"];
          GlobalConfig.PIRtoCCU = json["pirtoccu"];

          for (int i = 0; i < COLOR_COUNT; i++) {
            String colorStr = (json["color" + String(i)]).as<String>();
            if (colorStr != "")
              Dimmer2ColorDefinition[i] = colorStr;
          }

          GlobalConfig.NumLeds = (json["numleds"]).as<int>();
          if (GlobalConfig.NumLeds == 0)
            GlobalConfig.NumLeds = 1;

          GlobalConfig.DimBlink = (json["dimBlink"]).as<byte>();
          if (GlobalConfig.DimBlink == 0) GlobalConfig.DimBlink = 11;

          GlobalConfig.SelectedEOrder = (json["eorder"]).as<int>();
          GlobalConfig.LedBrightness = (json["brightness"]).as<byte>();
          if (GlobalConfig.LedBrightness < 5) GlobalConfig.LedBrightness = 255;

        } else {
          DEBUG("failed to load json config", "loadSystemConfig()", _slError);
        }
      }
      return true;
    } else {
      DEBUG("/" + configJsonFile + " not found.", "loadSystemConfig()", _slWarning);
      return false;
    }
    SPIFFS.end();
  } else {
    DEBUG("failed to mount FS", "loadSystemConfig()", _slError);
    return false;
  }
}

bool saveSystemConfig() {
  SPIFFS.begin();
  DEBUG("saving config", "saveSystemConfig()", _slInformational);
  DynamicJsonBuffer jsonBuffer;
  JsonObject& json = jsonBuffer.createObject();
  json["ip"] = ip;
  json["netmask"] = netmask;
  json["gw"] = gw;
  json["ccuip"] = GlobalConfig.CcuIp;
  json["devicename"] = GlobalConfig.DeviceName;
  json["numleds"] = GlobalConfig.NumLeds;
  json["eorder"] = GlobalConfig.SelectedEOrder;
  json["brightness"] = GlobalConfig.LedBrightness;
  json["restorestate"] = GlobalConfig.RestoreStateFromCCU;
  json["pirtoccu"] = GlobalConfig.PIRtoCCU;
  json["dimBlink"] = GlobalConfig.DimBlink;

  JsonArray& ledkeys = jsonBuffer.createArray();
  for (int i = 0; i < 16; i++) {
    ledkeys.add(LEDConfig.Keys[i]);
  };
  json["ledkeys"] = ledkeys;


  for (int i = 0; i < COLOR_COUNT; i++) {
    Dimmer2ColorDefinition[i].toUpperCase();
    json["color" + String(i)] = Dimmer2ColorDefinition[i];
  }

  SPIFFS.remove("/" + configJsonFile);
  File configFile = SPIFFS.open("/" + configJsonFile, "w");
  if (!configFile) {
    DEBUG("failed to open config file for writing", "saveSystemConfig()", _slError);
  }

#ifdef SERIALDEBUG
  json.printTo(Serial);
  Serial.println();
#endif
  json.printTo(configFile);
  configFile.close();

  SPIFFS.end();
}
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

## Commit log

2017-09-09 added images
    [Verdrahtungsplan.fzz]
2017-09-09 added front panel stl changed minimum brightness
    [Front.stl]
2017-09-12 added new images added 3d templates changed some wifimanager web
    [Front.stl, Grundplatte.stl, Rasterplatte.stl]
2017-10-01 added some images
    [mw_StatusDisplay-teil-2.stl, mw_StatusDisplay.stl]
2017-10-01 changed images
    [mw_StatusDisplay-teil-2.stl]
2017-10-07 changed web: dynamic table depending on number of leds changed web: separate file for css changed web: auto-refresh 10 seconds changed debugging output
2017-10-09 added missing http return for getValuesFromCCU
    [WebServer.ino, WemosD1_HomeMatic_StatusDisplay.ino]
2017-10-11 changed some debug information changed layout of status table in web added fritzing file for 16keys
    [16keys.fzz]
2017-10-13 added key config function ResistorConfigKeys()
2017-10-13 changed ResistorConfigKeys()
2017-10-14 final version added some images
    [16keys.fzz]
2018-03-30 fixed wiring from +5V to +3.3V
    [16keys.fzz]
2018-04-02 corrected some issues (#8) for better network reachability
    [HomeMatic.ino, WemosD1_HomeMatic_StatusDisplay.ino, WifiManager.ino]
